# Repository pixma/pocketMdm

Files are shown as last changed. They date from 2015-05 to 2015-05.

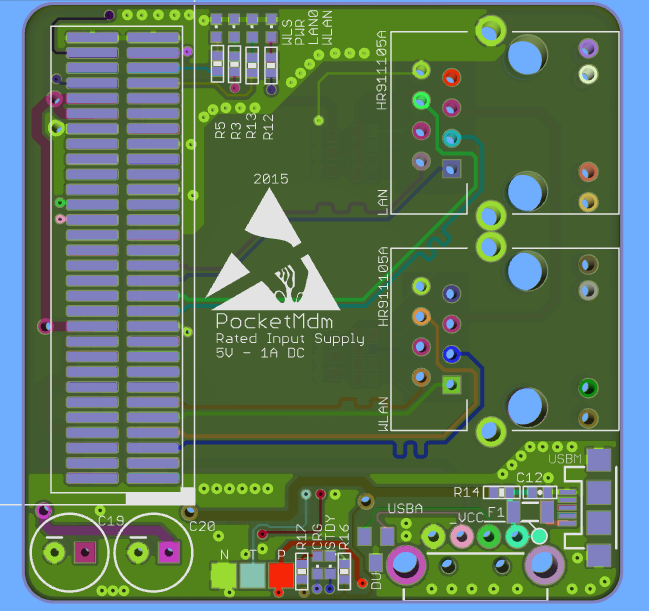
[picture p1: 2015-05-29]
revDR1/Capture-1.PNG

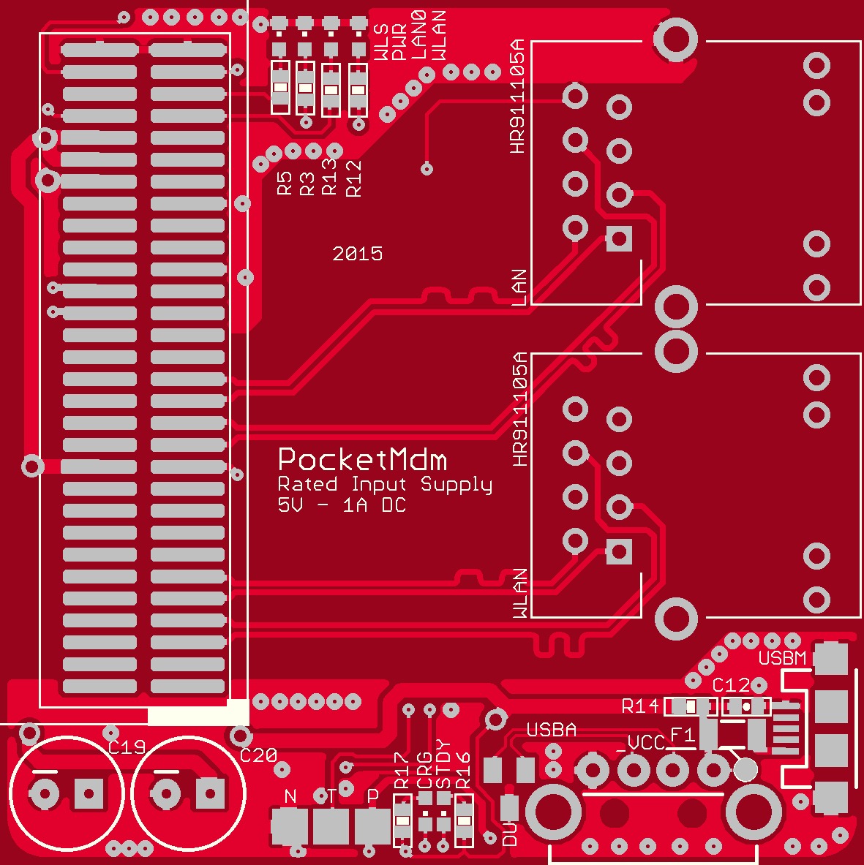
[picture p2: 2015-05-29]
revDR1/eagleUp_pocketmdm_board_top.jpg

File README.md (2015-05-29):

# pocketMdm
A pocket router / AP / Switch, also runs with OpenWRT, A perfect Development kit for development around OpenWRT.

Current Version:
- rev D R1

Description
- 1 x WLAN
- 1 x LAN
- Battery backup for 1000mAh Li ion battery + Recharge battery functionality
- 1 x OTG
- 5 VDC, 1000mA Input rated
- UART Communication pad provided for development.
- Build around SKW 75 from Skylabs

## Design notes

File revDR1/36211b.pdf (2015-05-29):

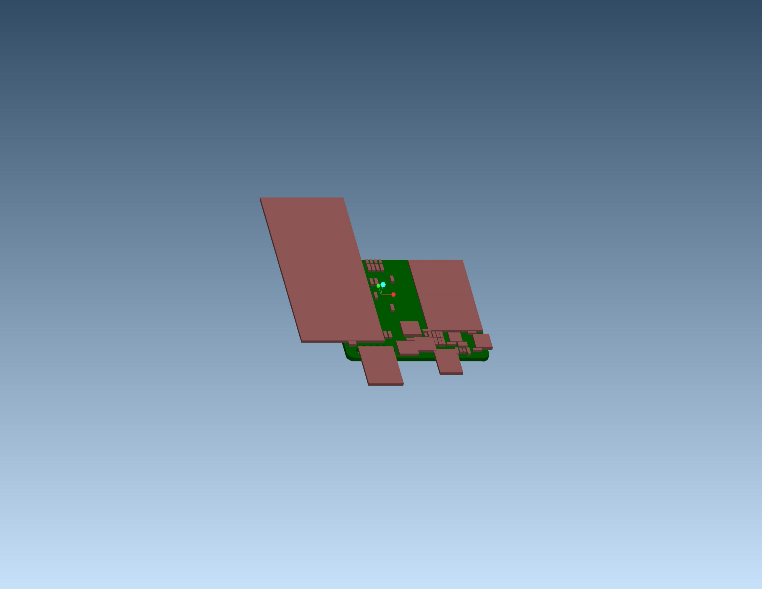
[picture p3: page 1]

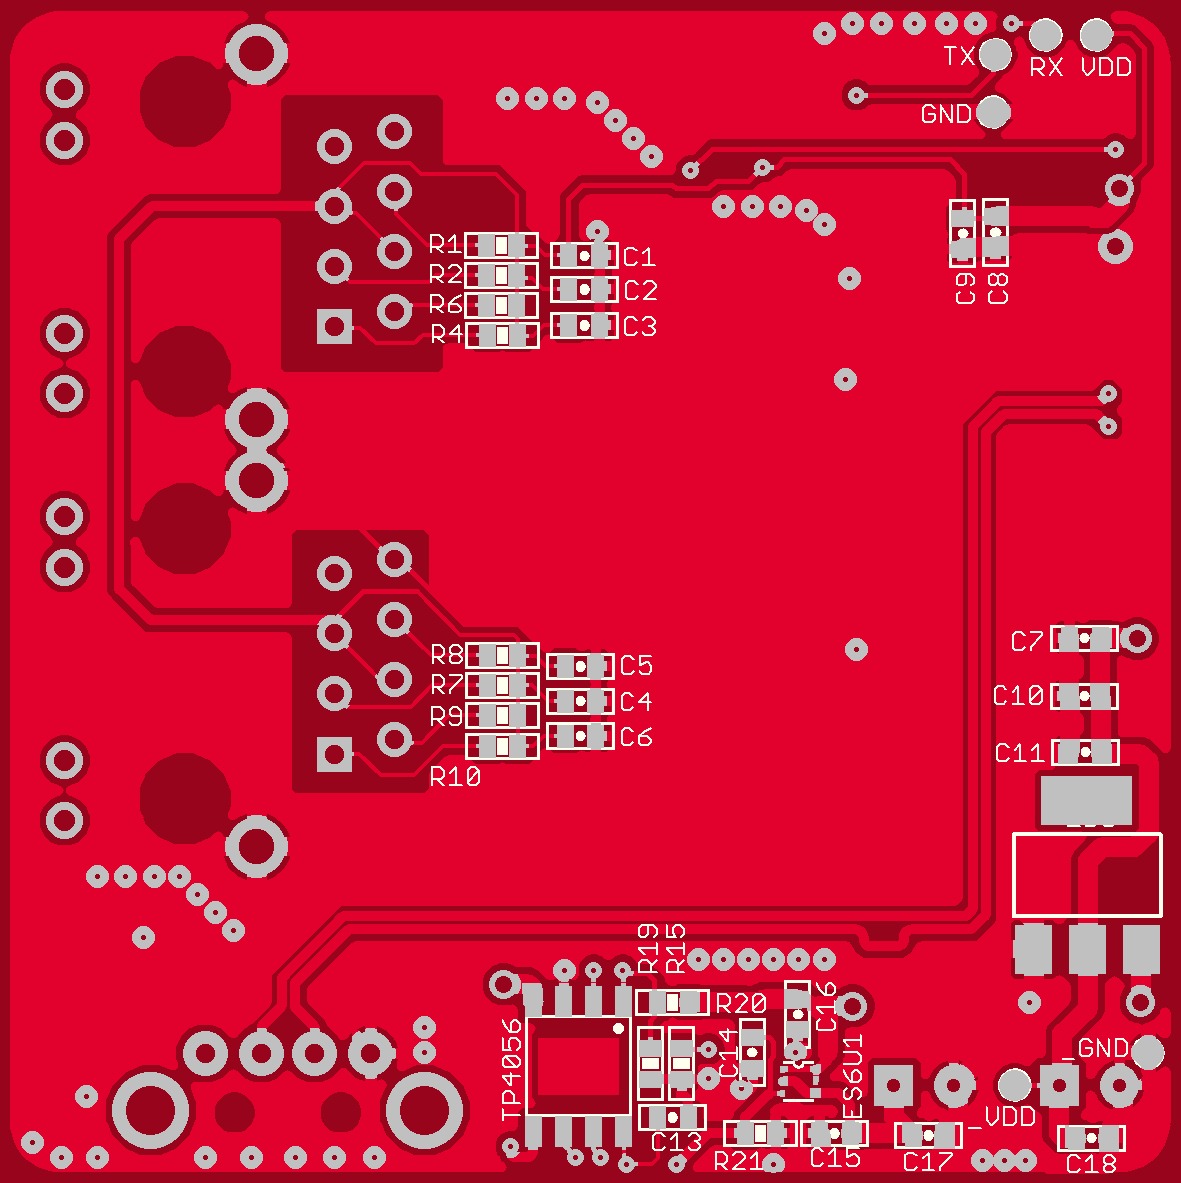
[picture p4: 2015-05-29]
revDR1/eagleUp_pocketmdm_board_bottom.jpg

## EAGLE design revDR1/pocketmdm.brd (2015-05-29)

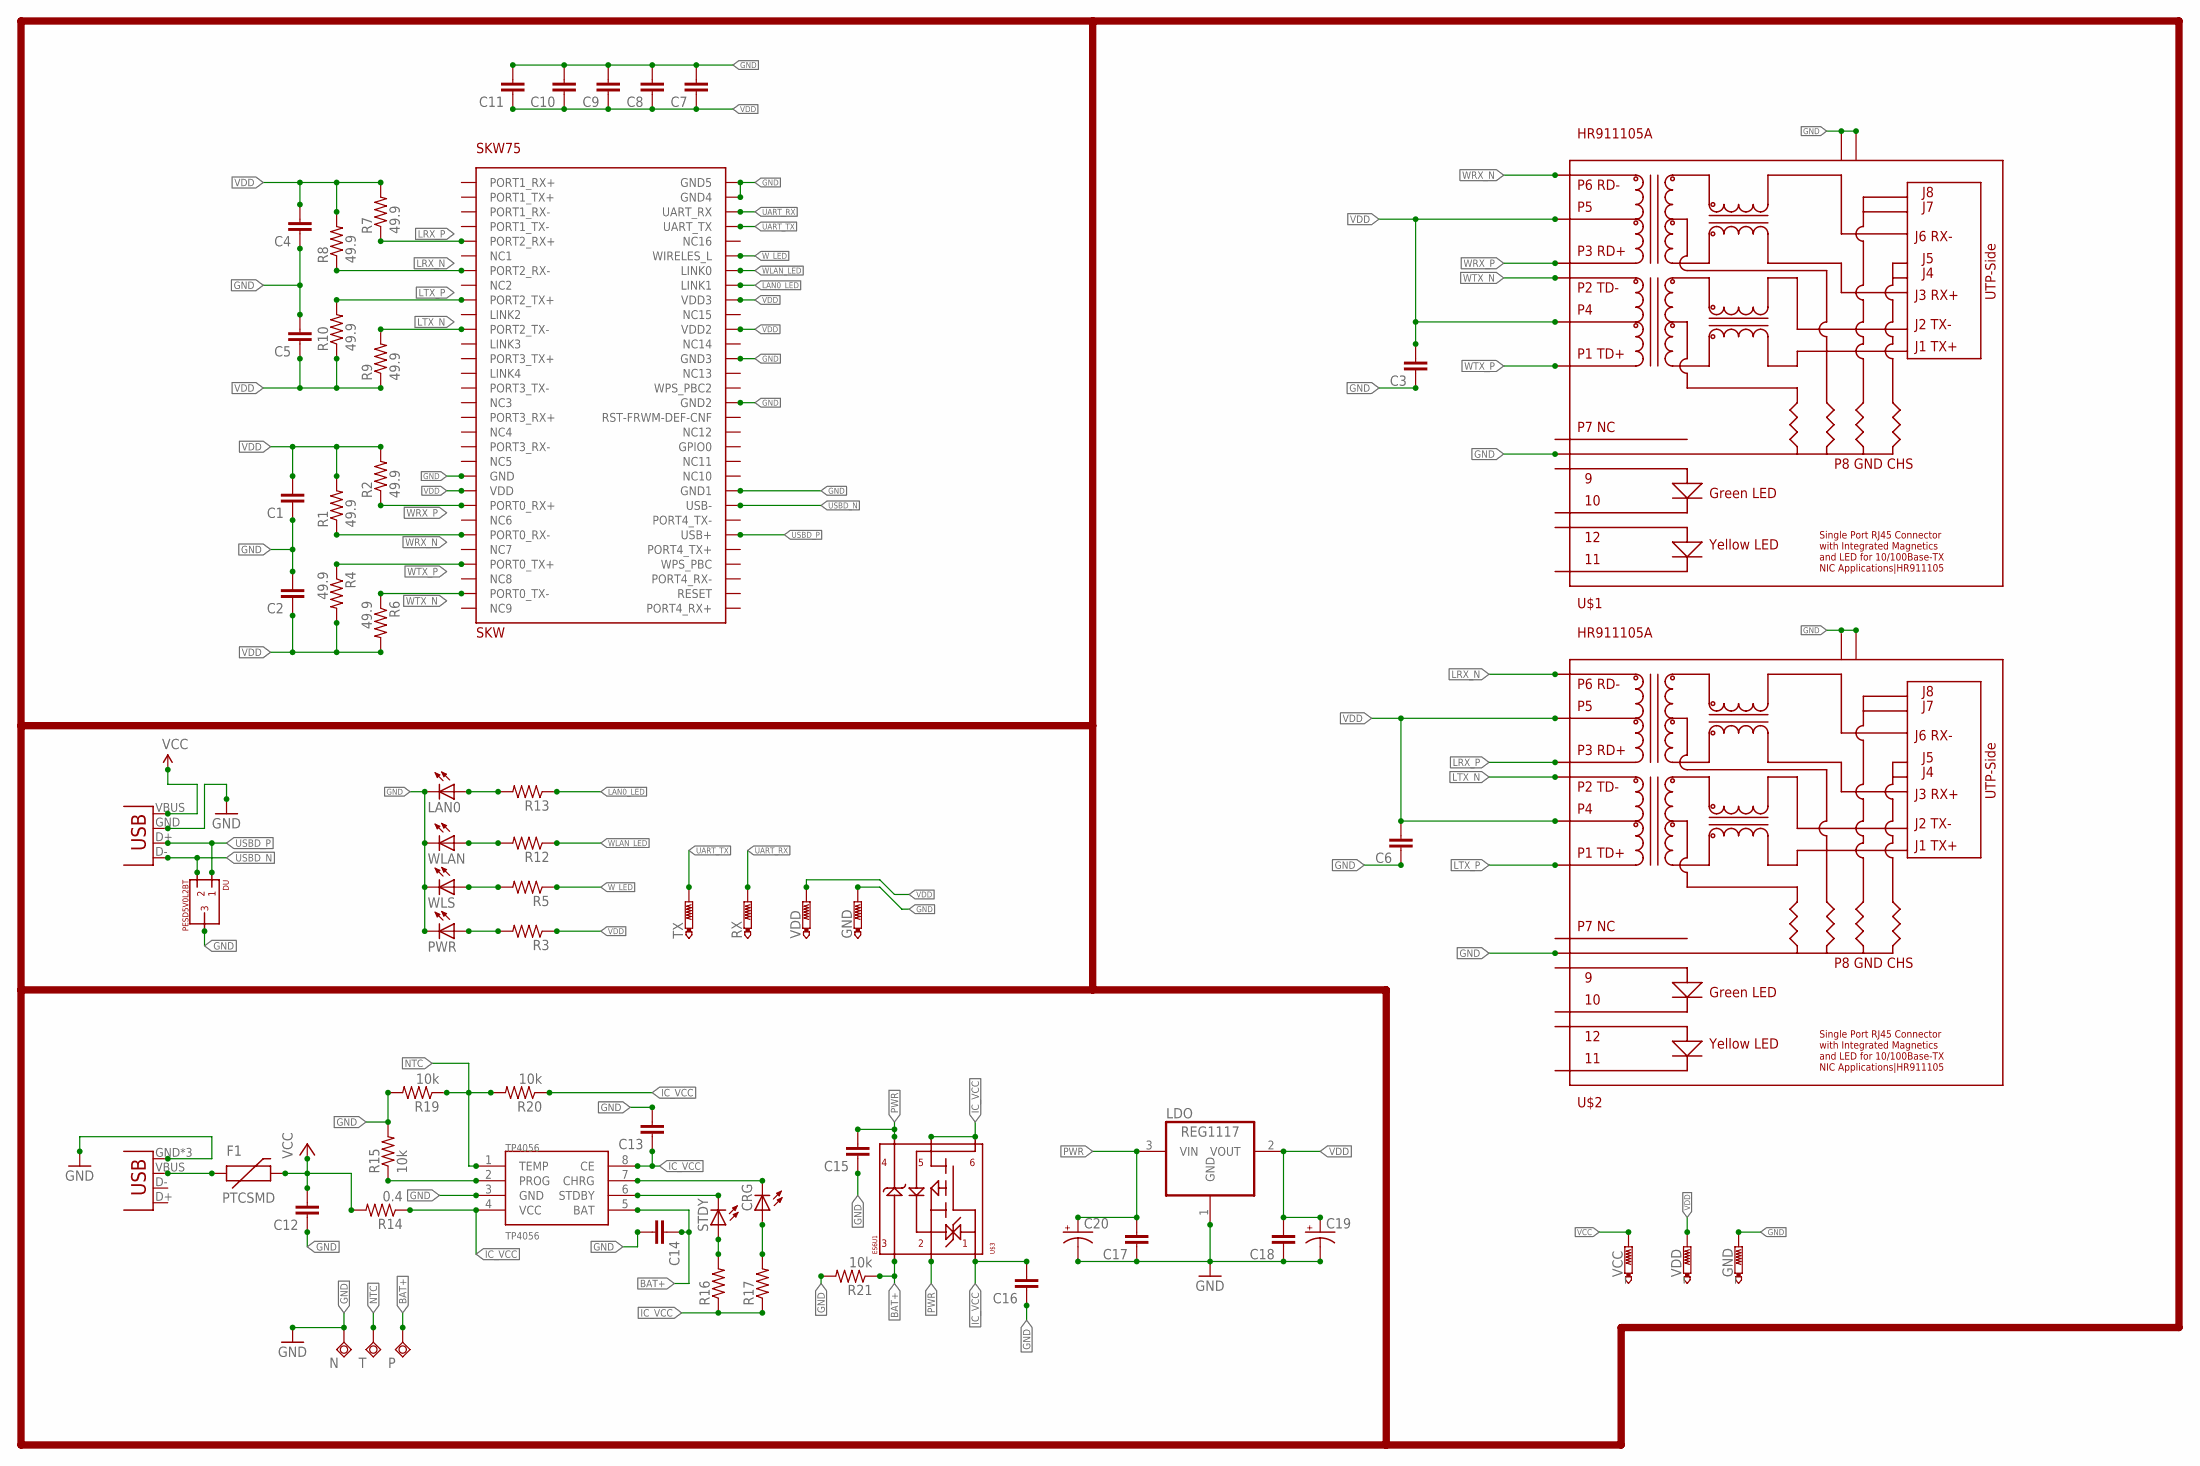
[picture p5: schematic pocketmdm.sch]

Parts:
C1, C2, C3, C4, C5, C6, C7, C8, C9, C10, C11, C12, C13, C14, C15, C16, C17, C18: CAP0402-CAP; 0402-CAP
C19, C20: CAP_POLPTH1; CPOL-RADIAL-100UF-25V
CRG: LEDCHIPLED_0603; CHIPLED_0603
DU: PESD5V0L2BT; SOT23
F1: PTCSMD; PTC-1206
GND: PTR1B1,27; B1,27
LAN0: LEDCHIPLED_0603; CHIPLED_0603
LDO: REG1117; SOT223
N: TPSQTP20SQ; TP20SQ
P: TPSQTP20SQ; TP20SQ
PWR: LEDCHIPLED_0603; CHIPLED_0603
R1, R2, R4, R6, R7, R8, R9, R10: 49.9; 0402-RES
R3, R5, R12, R13, R16, R17: RESISTOR0402-RES; 0402-RES
R14: 0.4; 0402-RES
R15, R19, R20, R21: 10k; 0402-RES
RX: PTR1B1,27; B1,27
SKW: SKW75; CON-60-127MMPTH
STDY: LEDCHIPLED_0603; CHIPLED_0603
T: TPSQTP20SQ; TP20SQ
TP4056: TP4056; SOP-8
TX: PTR1B1,27; B1,27
U$1, U$2: HR911105A
U$3: ES6U1; WEMT6
USBA: USB-A-H
USBM: USB-MICROB
VDD: PTR1B1,27; B1,27
WLAN: LEDCHIPLED_0603; CHIPLED_0603
WLS: LEDCHIPLED_0603; CHIPLED_0603
_GND: PTR1B1,27; B1,27
_VCC: PTR1B1,27; B1,27
_VDD: PTR1B1,27; B1,27

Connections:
BAT+: C14.1, P.TP, R21.1, TP4056.5 (BAT), U$3.P$3
GND: C1.1, C2.2, C3.1, C4.1, C5.2, C6.1, C7.2, C8.2, C9.2, C10.2, C11.2, C12.1, C13.2, C14.2, C15.1, C16.1, C17.1, C18.1, C19.2 (-), C20.2 (-), DU.3, GND.TP, LAN0.C, LDO.1 (GND), N.TP, PWR.C, R15.2, R19.2, R21.2, SKW.P$21 (GND), SKW.P$39 (GND1), SKW.P$45 (GND2), SKW.P$48 (GND3), SKW.P$59 (GND4), SKW.P$60 (GND5), TP4056.3 (GND), U$1.P$8, U$1.P$13, U$1.P$14, U$2.P$8, U$2.P$13, U$2.P$14, USBA.GND (VBUS), USBM.GND, USBM.MT1 (GND), USBM.MT2 (GND), WLAN.C, WLS.C, _GND.TP
IC_VCC: C13.1, C16.2, R14.1, R16.1, R17.1, R20.1, TP4056.4 (VCC), TP4056.8 (CE), U$3.P$1, U$3.P$5, U$3.P$6
LAN0_LED: R13.1, SKW.P$53 (LINK1)
LRX_N: R8.1, SKW.P$7 (PORT2_RX-), U$2.P$6
LRX_P: R7.1, SKW.P$5 (PORT2_RX+), U$2.P$3
LTX_N: R9.2, SKW.P$11 (PORT2_TX-), U$2.P$2
LTX_P: R10.2, SKW.P$9 (PORT2_TX+), U$2.P$1
unnamed: CRG.C, TP4056.7 (CHRG)
unnamed: F1.1, USBM.VBUS
unnamed: R15.1, TP4056.2 (PROG)
unnamed: STDY.C, TP4056.6 (STDBY)
unnamed: PWR.A, R3.2
unnamed: R5.2, WLS.A
unnamed: R12.2, WLAN.A
unnamed: R16.2, STDY.A
unnamed: CRG.A, R17.2
unnamed: LAN0.A, R13.2
NTC: R19.1, R20.2, T.TP, TP4056.1 (TEMP)
PWR: C15.2, C17.2, C20.1 (+), LDO.3 (VIN), U$3.P$2, U$3.P$4
UART_RX: RX.TP, SKW.P$58 (UART_RX)
UART_TX: SKW.P$57 (UART_TX), TX.TP
USBD_N: DU.2, SKW.P$38 (USB-), USBA.D- (D+)
USBD_P: DU.1, SKW.P$36 (USB+), USBA.D+ (D-)
VCC: C12.2, F1.2, R14.2, USBA.VBUS (GND), _VCC.TP
VDD: C1.2, C2.1, C3.2, C4.2, C5.1, C6.2, C7.1, C8.1, C9.1, C10.1, C11.1, C18.2, C19.1 (+), LDO.2 (VOUT), R1.2, R2.2, R3.1, R4.2, R6.2, R7.2, R8.2, R9.1, R10.1, SKW.P$22 (VDD), SKW.P$50 (VDD2), SKW.P$52 (VDD3), U$1.P$4, U$1.P$5, U$2.P$4, U$2.P$5, VDD.TP, _VDD.TP
WLAN_LED: R12.1, SKW.P$54 (LINK0)
WRX_N: R1.1, SKW.P$25 (PORT0_RX-), U$1.P$6
WRX_P: R2.1, SKW.P$23 (PORT0_RX+), U$1.P$3
WTX_N: R6.1, SKW.P$29 (PORT0_TX-), U$1.P$2
WTX_P: R4.1, SKW.P$27 (PORT0_TX+), U$1.P$1
W_LED: R5.1, SKW.P$55 (WIRELES_L)

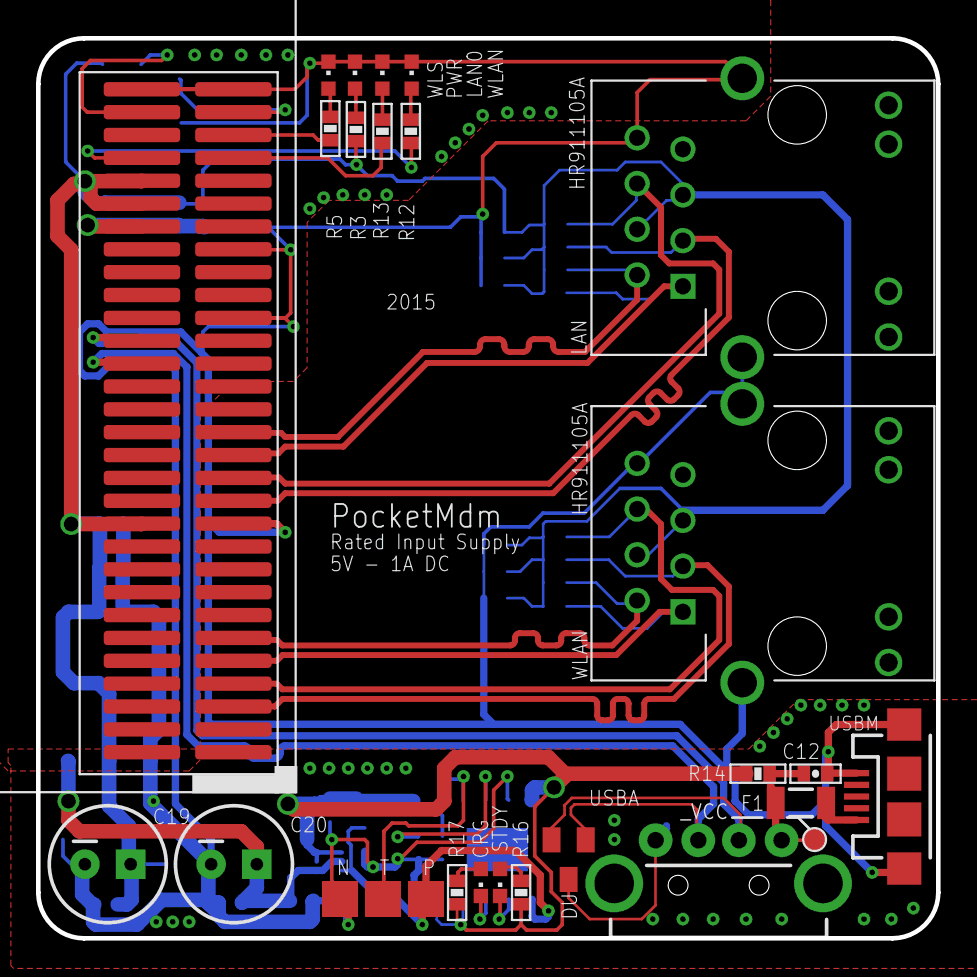
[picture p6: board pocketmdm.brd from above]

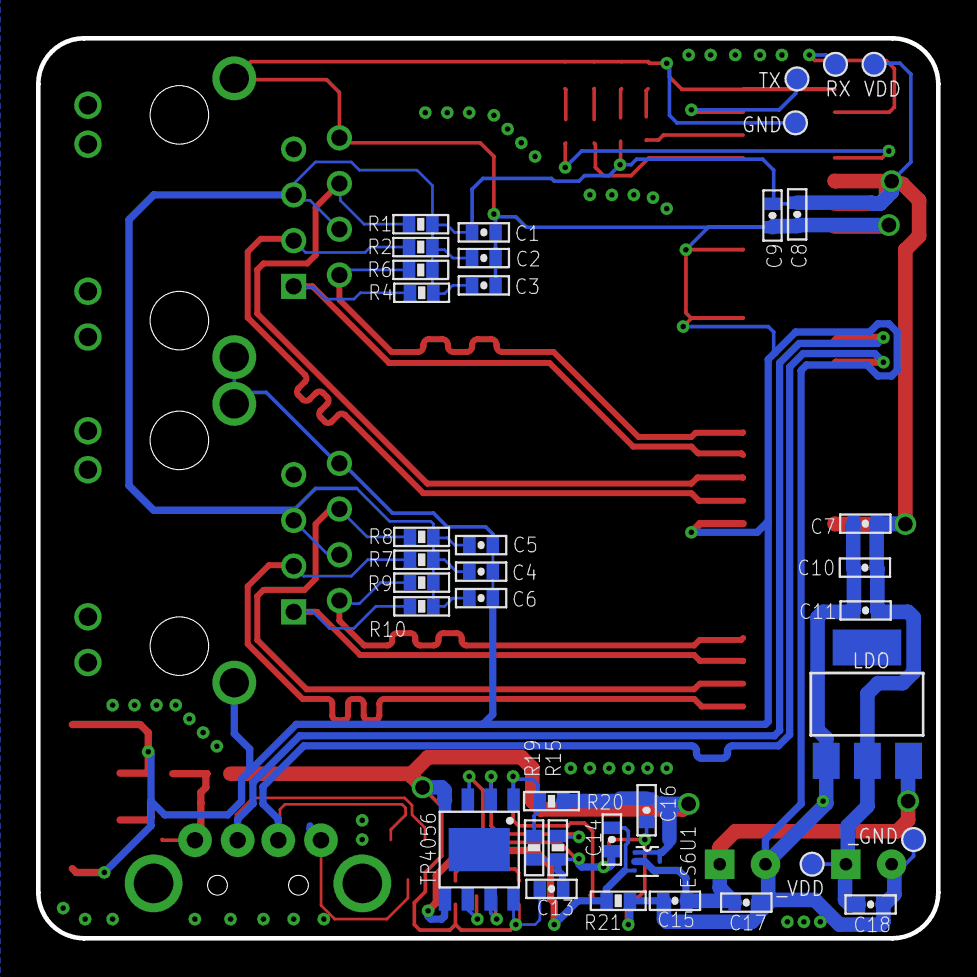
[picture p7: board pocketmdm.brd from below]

Board: 2 copper layers, 50.0 x 50.0 mm, 65 parts (38 on the bottom side), 32 nets.

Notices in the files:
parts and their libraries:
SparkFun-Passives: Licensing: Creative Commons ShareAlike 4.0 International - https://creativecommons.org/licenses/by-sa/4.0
